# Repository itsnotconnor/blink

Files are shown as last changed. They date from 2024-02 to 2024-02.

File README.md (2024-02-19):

# Simple LED Blink PCB with RP2040

## Features
* RP2040 Bootloader switch
* Single WS2182 RGB LED w/ logic level shifter
* ADC inputs for future sensors
* GPIO breakout
* Program Port

## Design reference from raspberry pi
* https://datasheets.raspberrypi.com/rp2040/hardware-design-with-rp2040.pdf

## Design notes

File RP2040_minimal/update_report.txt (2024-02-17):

Info: Processing symbol 'R3:Capacitor_SMD:C_0402_1005Metric'.
Info: Processing symbol 'H2:MountingHole:MountingHole_2.7mm_M2.5'.
Info: Processing symbol 'H3:MountingHole:MountingHole_2.7mm_M2.5'.
Info: Processing symbol 'H4:MountingHole:MountingHole_2.7mm_M2.5'.
Info: Processing symbol 'J1:RP2040_minimal:USB_Micro-B_Amphenol_10103594-0001LF_Horizontal_modified'.
Info: Processing symbol 'C1:Capacitor_SMD:C_0805_2012Metric'.
Info: Processing symbol 'J3:Connector_PinHeader_2.54mm:PinHeader_2x18_P2.54mm_Vertical'.
Info: Processing symbol 'J4:Connector_PinHeader_2.54mm:PinHeader_2x03_P2.54mm_Horizontal'.
Info: Processing symbol 'R1:Capacitor_SMD:C_0402_1005Metric'.
Info: Processing symbol 'R2:Capacitor_SMD:C_0402_1005Metric'.
Info: Processing symbol 'J2:Connector_PinHeader_2.54mm:PinHeader_1x02_P2.54mm_Vertical'.
Info: Processing symbol 'R4:Capacitor_SMD:C_0402_1005Metric'.
Info: Processing symbol 'R5:Capacitor_SMD:C_0402_1005Metric'.
Info: Processing symbol 'R6:Capacitor_SMD:C_0402_1005Metric'.
Info: Processing symbol 'U1:Package_TO_SOT_SMD:SOT-223-3_TabPin2'.
Info: Processing symbol 'U2:Package_SO:SOIC-8_5.23x5.23mm_P1.27mm'.
Info: Processing symbol 'U3:RP2040_minimal:RP2040-QFN-56'.
Info: Processing symbol 'U4:Package_DIP:DIP-14_W7.62mm'.
Info: Processing symbol 'Y1:RP2040_minimal:Crystal_SMD_HC49-US'.
Info: Processing symbol 'D2:LED_SMD:LED_WS2812_PLCC6_5.0x5.0mm_P1.6mm'.
Info: Processing symbol 'C2:Capacitor_SMD:C_0402_1005Metric'.
Info: Processing symbol 'C3:Capacitor_SMD:C_0402_1005Metric'.
Info: Processing symbol 'C4:Capacitor_SMD:C_0805_2012Metric'.
Info: Processing symbol 'C5:Capacitor_SMD:C_0402_1005Metric'.
Info: Processing symbol 'C6:Capacitor_SMD:C_0402_1005Metric'.
Info: Processing symbol 'C7:Capacitor_SMD:C_0402_1005Metric'.
Info: Processing symbol 'C8:Capacitor_SMD:C_0402_1005Metric'.
Info: Processing symbol 'C9:Capacitor_SMD:C_0402_1005Metric'.
Info: Processing symbol 'C10:Capacitor_SMD:C_0402_1005Metric'.
Info: Processing symbol 'C11:Capacitor_SMD:C_0402_1005Metric'.
Info: Processing symbol 'C12:Capacitor_SMD:C_0402_1005Metric'.
Info: Processing symbol 'H1:MountingHole:MountingHole_2.7mm_M2.5'.
Info: Processing symbol 'C18:Capacitor_SMD:C_0402_1005Metric'.
Info: Processing symbol 'C17:Capacitor_SMD:C_0805_2012Metric'.
Info: Processing symbol 'C16:Capacitor_SMD:C_0402_1005Metric'.
Info: Processing symbol 'C15:Capacitor_SMD:C_0402_1005Metric'.
Info: Processing symbol 'C14:Capacitor_SMD:C_0402_1005Metric'.
Info: Processing symbol 'C13:Capacitor_SMD:C_0402_1005Metric'.
Changed REF** reference designator to J4.
Added J4 (footprint 'Connector_PinHeader_2.54mm:PinHeader_2x03_P2.54mm_Horizontal').
Updated J4 properties.
Changed J4 value from PinHeader_2x03_P2.54mm_Horizontal to Conn_02x03_Top_Bottom.
Updated J4 symbol association from  to /17aea721-951e-4fd8-86f5-0ff4e2e6ff19.
Connected J4 pin 6 to GND.
Connected J4 pin 5 to /GPIO17.
Connected J4 pin 4 to /GPIO18.
Connected J4 pin 3 to /SWD.
Connected J4 pin 2 to /SWCLK.
Connected J4 pin 1 to /RUN.

Info: Total warnings: 0, errors: 0.

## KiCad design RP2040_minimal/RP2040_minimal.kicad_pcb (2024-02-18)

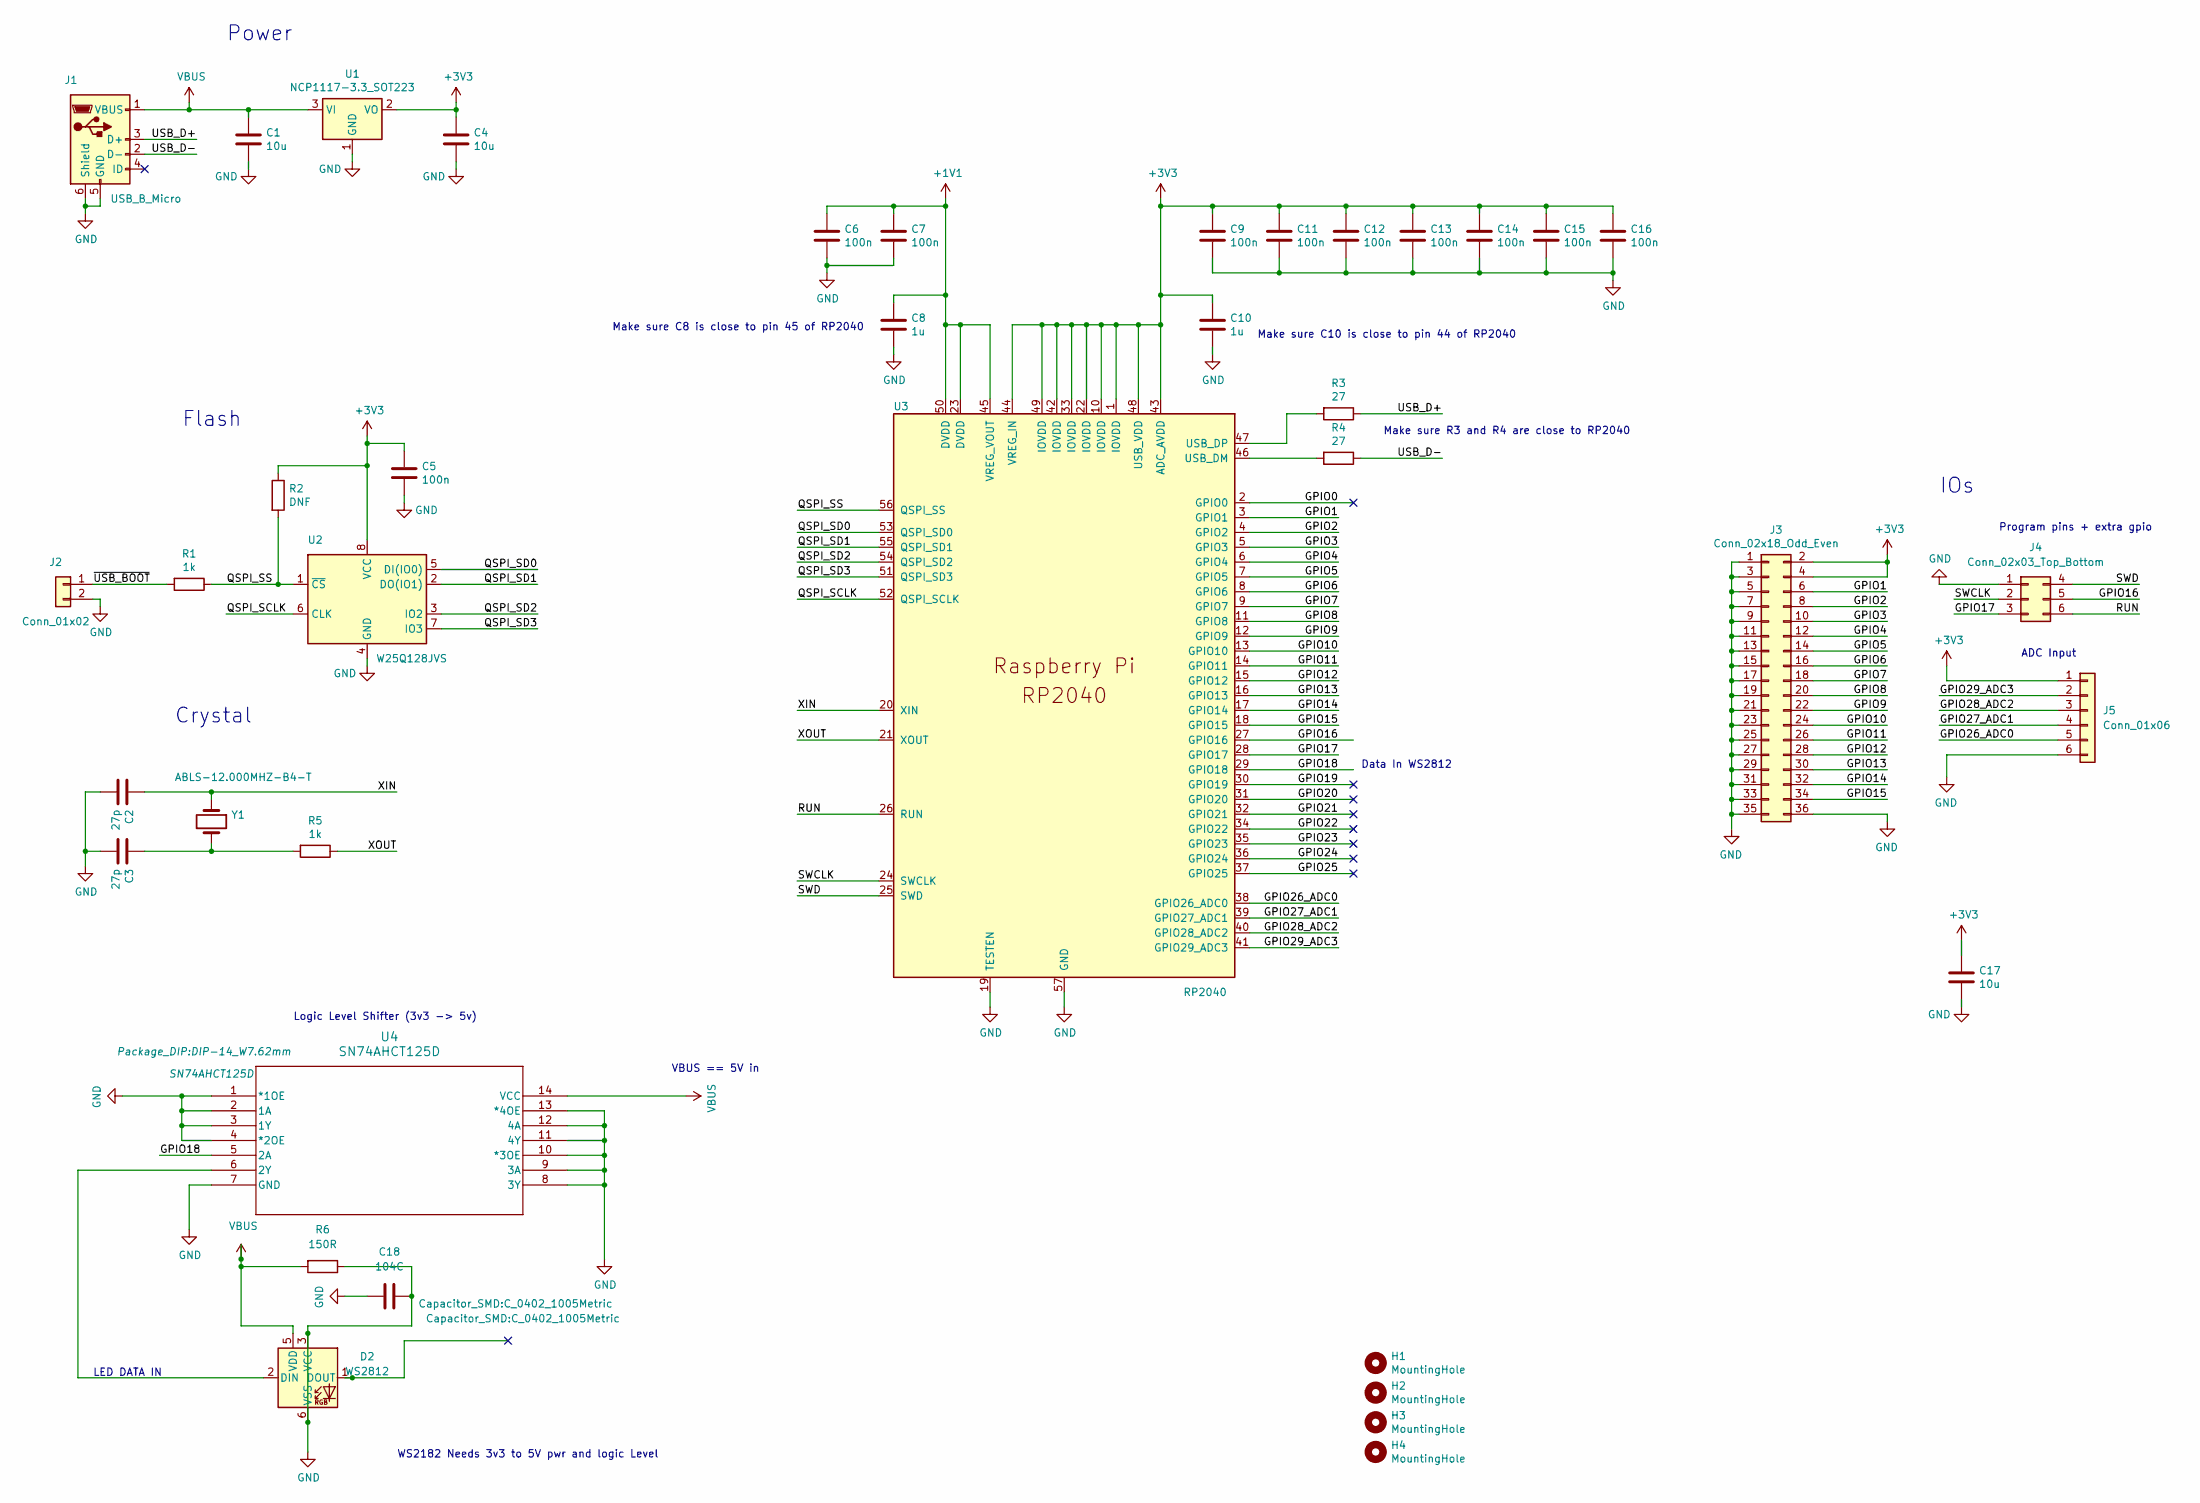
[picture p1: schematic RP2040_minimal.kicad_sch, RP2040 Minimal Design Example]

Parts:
C1, C4, C17: 10u; C_0805_2012Metric
C2, C3: 27p; C_0402_1005Metric
C5, C6, C7, C9, C11, C12, C13, C14, C15, C16: 100n; C_0402_1005Metric
C8, C10: 1u; C_0402_1005Metric
C18: 104C; C_0402_1005Metric
D2: WS2812; LED_WS2812_PLCC6_5.0x5.0mm_P1.6mm
H1, H2, H3, H4: MountingHole; MountingHole_2.7mm_M2.5
J1: USB_B_Micro; USB_Micro-B_Amphenol_10103594-0001LF_Horizontal_modified
J2: Conn_01x02; PinHeader_1x02_P2.54mm_Vertical
J3: Conn_02x18_Odd_Even; PinHeader_2x18_P2.54mm_Vertical
J4: Conn_02x03_Top_Bottom; PinHeader_2x03_P2.54mm_Horizontal
J5: Conn_01x06; PinHeader_1x06_P2.54mm_Vertical
R1, R5: 1k; C_0402_1005Metric
R2: DNF; C_0402_1005Metric
R3, R4: 27; C_0402_1005Metric
R6: 150R; C_0402_1005Metric
U1: NCP1117-3.3_SOT223; SOT-223-3_TabPin2
U2: W25Q128JVS; SOIC-8_5.23x5.23mm_P1.27mm
U3: RP2040; RP2040-QFN-56
U4: SN74AHCT125D; DIP-14_W7.62mm
Y1: ABLS-12.000MHZ-B4-T; Crystal_SMD_HC49-US

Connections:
+1V1: C6.1, C7.1, C8.1, U3.23 (DVDD), U3.45 (VREG_VOUT), U3.50 (DVDD)
+3V3: C4.1, C5.1, C9.1, C10.1, C11.1, C12.1, C13.1, C14.1, C15.1, C16.1, C17.1, J3.2, J3.4, J5.1, R2.1, U1.2 (VO), U2.8 (VCC), U3.1 (IOVDD), U3.10 (IOVDD), U3.22 (IOVDD), U3.33 (IOVDD), U3.42 (IOVDD), U3.43 (ADC_AVDD), U3.44 (VREG_IN), U3.48 (USB_VDD), U3.49 (IOVDD)
/GPIO0: U3.2 (GPIO0)
/GPIO1: J3.6, U3.3 (GPIO1)
/GPIO2: J3.8, U3.4 (GPIO2)
/GPIO3: J3.10, U3.5 (GPIO3)
/GPIO4: J3.12, U3.6 (GPIO4)
/GPIO5: J3.14, U3.7 (GPIO5)
/GPIO6: J3.16, U3.8 (GPIO6)
/GPIO7: J3.18, U3.9 (GPIO7)
/GPIO8: J3.20, U3.11 (GPIO8)
/GPIO9: J3.22, U3.12 (GPIO9)
/GPIO10: J3.24, U3.13 (GPIO10)
/GPIO11: J3.26, U3.14 (GPIO11)
/GPIO12: J3.28, U3.15 (GPIO12)
/GPIO13: J3.30, U3.16 (GPIO13)
/GPIO14: J3.32, U3.17 (GPIO14)
/GPIO15: J3.34, U3.18 (GPIO15)
/GPIO16: J4.5, U3.27 (GPIO16)
/GPIO17: J4.3, U3.28 (GPIO17)
/GPIO18: U3.29 (GPIO18), U4.5 (2A)
/GPIO19: U3.30 (GPIO19)
/GPIO20: U3.31 (GPIO20)
/GPIO21: U3.32 (GPIO21)
/GPIO22: U3.34 (GPIO22)
/GPIO23: U3.35 (GPIO23)
/GPIO24: U3.36 (GPIO24)
/GPIO25: U3.37 (GPIO25)
/GPIO26_ADC0: J5.5, U3.38 (GPIO26_ADC0)
/GPIO27_ADC1: J5.4, U3.39 (GPIO27_ADC1)
/GPIO28_ADC2: J5.3, U3.40 (GPIO28_ADC2)
/GPIO29_ADC3: J5.2, U3.41 (GPIO29_ADC3)
/QSPI_SCLK: U2.6 (CLK), U3.52 (QSPI_SCLK)
/QSPI_SD0: U2.5 (DI(IO0)), U3.53 (QSPI_SD0)
/QSPI_SD1: U2.2 (DO(IO1)), U3.55 (QSPI_SD1)
/QSPI_SD2: U2.3 (IO2), U3.54 (QSPI_SD2)
/QSPI_SD3: U2.7 (IO3), U3.51 (QSPI_SD3)
/QSPI_SS: R1.1, R2.2, U2.1 (~CS), U3.56 (QSPI_SS)
/RUN: J4.6, U3.26 (RUN)
/SWCLK: J4.2, U3.24 (SWCLK)
/SWD: J4.4, U3.25 (SWD)
/USB_D+: J1.3 (D+), R3.1
/USB_D-: J1.2 (D-), R4.1
/XIN: C2.1, U3.20 (XIN), Y1.1
/XOUT: R5.1, U3.21 (XOUT)
/~USB_BOOT: J2.1, R1.2
GND: C1.2, C2.2, C3.2, C4.2, C5.2, C6.2, C7.2, C8.2, C9.2, C10.2, C11.2, C12.2, C13.2, C14.2, C15.2, C16.2, C17.2, C18.1, C18.2, D2.3 (VCC), D2.6 (VSS), J1.5 (GND), J1.6 (Shield), J2.2, J3.1, J3.3, J3.5, J3.7, J3.9, J3.11, J3.13, J3.15, J3.17, J3.19, J3.21, J3.23, J3.25, J3.27, J3.29, J3.31, J3.33, J3.35, J3.36, J4.1, J5.6, R6.1, U1.1 (GND), U2.4 (GND), U3.19 (TESTEN), U3.57 (GND), U4.1 (*1OE), U4.2 (1A), U4.3 (1Y), U4.4 (*2OE), U4.7 (GND), U4.8 (3Y), U4.9 (3A), U4.10 (*3OE), U4.11 (4Y), U4.12 (4A), U4.13 (*4OE)
unnamed: C3.1, R5.2, Y1.2
unnamed: D2.2 (DIN), U4.6 (2Y)
unnamed: R4.2, U3.46 (USB_DM)
unnamed: R3.2, U3.47 (USB_DP)
VBUS: C1.1, D2.5 (VDD), J1.1 (VBUS), R6.2, U1.3 (VI), U4.14 (VCC)

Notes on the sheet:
ADC Input
LED DATA IN
Logic Level Shifter (3v3 -> 5v)
Make sure C10 is close to pin 44 of RP2040
Make sure C8 is close to pin 45 of RP2040
Crystal
Data In WS2812
WS2182 Needs 3v3 to 5V pwr and logic Level
Program pins + extra gpio
Flash
Make sure R3 and R4 are close to RP2040
IOs
Power
VBUS == 5V in

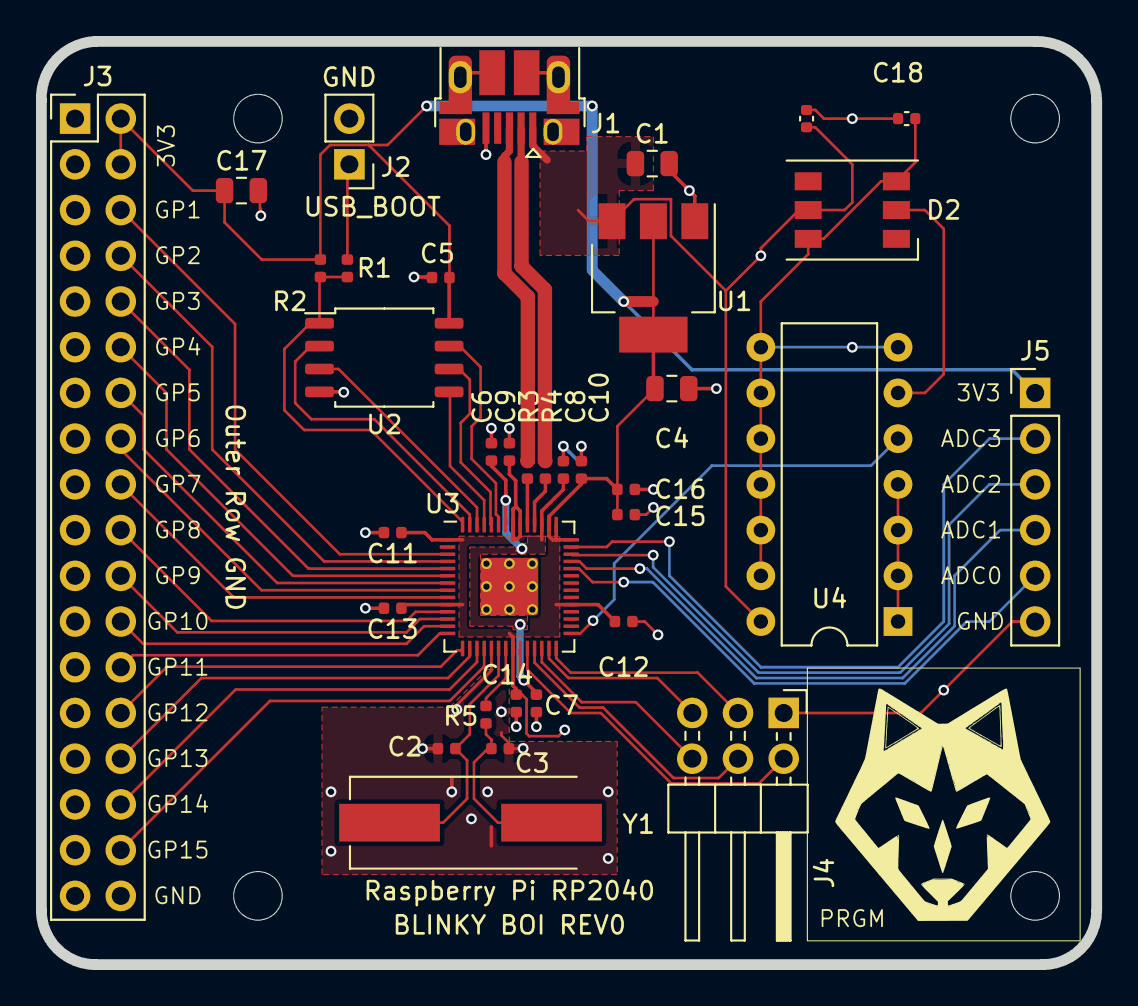
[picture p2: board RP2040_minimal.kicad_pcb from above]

Board: 2 copper layers, 58.6 x 51.3 mm, 39 parts (0 on the bottom side), 44 nets.

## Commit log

2024-02-17 init blinky boi
    [RP2040_minimal.kicad_pcb, RP2040_minimal.kicad_sch, RP2040_minimal.sch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]
2024-02-18 moved logo and resolved schematic DRC
    [RP2040_minimal.kicad_pcb, RP2040_minimal.kicad_sch]
2024-02-18 moved digital led trace to back of board
    [RP2040_minimal.kicad_pcb]
